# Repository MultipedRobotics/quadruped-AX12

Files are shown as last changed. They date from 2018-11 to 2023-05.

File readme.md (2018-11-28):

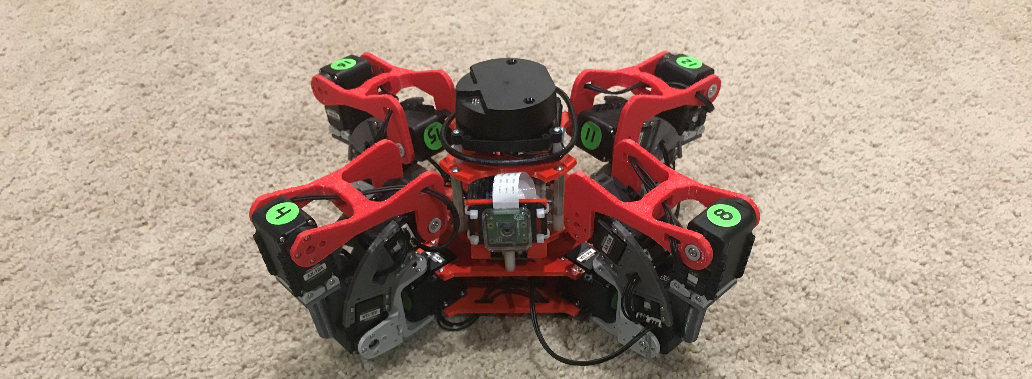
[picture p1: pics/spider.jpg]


# AX-12A Quadruped

Features:

- Robotis AX-12A servos
- 4 legs
    - 4 servos per leg for added degrees of freedom
- Raspberry Pi 3 controlled w/camera
- Robotis lidar for obstacle avoidance and SLAM
- 12V power system
- Externally powered so no limit on run time
    - A battery could be designed and integrated

# Hardware

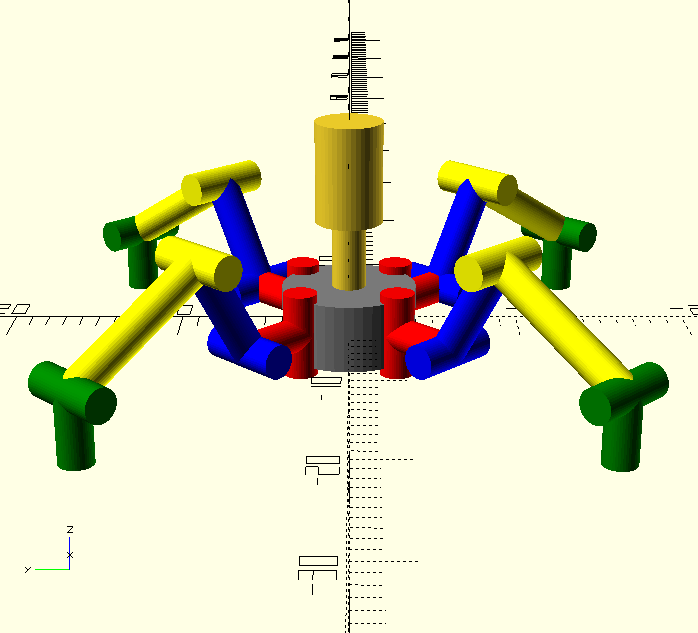
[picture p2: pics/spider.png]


**Still under development**

- [Mechanical Hardware](mechanical/)
- [Electrical Hardware](electrical/)

# Software

Uses [multiped library](https://github.com/MultipedRobotics/multiped/) to control it.

Other SW is TBD until the design is finished

# Software is MIT License

**Copyright (c) 2018 Kevin J. Walchko**

Permission is hereby granted, free of charge, to any person obtaining a
copy of this software and associated documentation files (the
"Software"), to deal in the Software without restriction, including
without limitation the rights to use, copy, modify, merge, publish,
distribute, sublicense, and/or sell copies of the Software, and to
permit persons to whom the Software is furnished to do so, subject to
the following conditions:

The above copyright notice and this permission notice shall be included
in all copies or substantial portions of the Software.

THE SOFTWARE IS PROVIDED "AS IS", WITHOUT WARRANTY OF ANY KIND,
EXPRESS OR IMPLIED, INCLUDING BUT NOT LIMITED TO THE WARRANTIES OF
MERCHANTABILITY, FITNESS FOR A PARTICULAR PURPOSE AND NONINFRINGEMENT.
IN NO EVENT SHALL THE AUTHORS OR COPYRIGHT HOLDERS BE LIABLE FOR ANY
CLAIM, DAMAGES OR OTHER LIABILITY, WHETHER IN AN ACTION OF CONTRACT,
TORT OR OTHERWISE, ARISING FROM, OUT OF OR IN CONNECTION WITH THE
SOFTWARE OR THE USE OR OTHER DEALINGS IN THE SOFTWARE.

---

<p align="center">
    <a rel="license" href="http://creativecommons.org/licenses/by-sa/4.0/">
        
    </a>
    <br />The hardware (mechanical/electrical/documentation) is licensed under a <a rel="license" href="http://creativecommons.org/licenses/by-sa/4.0/">Creative Commons Attribution-ShareAlike 4.0 International License</a>.
</p>

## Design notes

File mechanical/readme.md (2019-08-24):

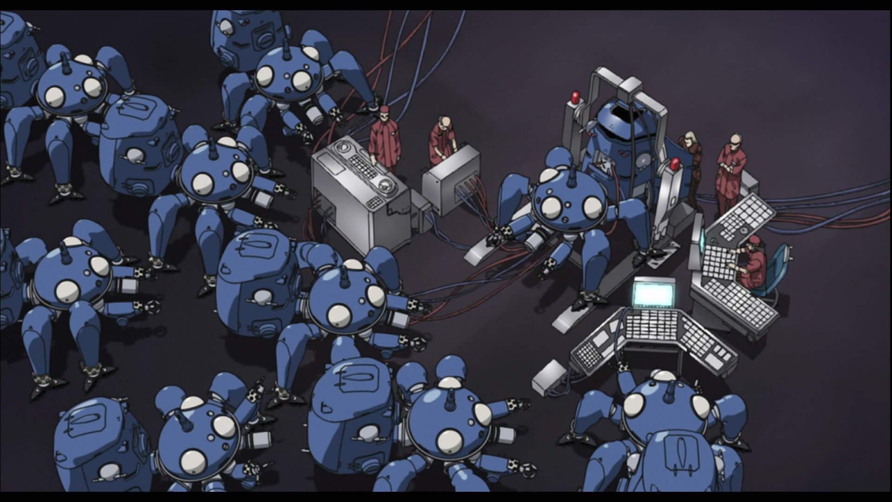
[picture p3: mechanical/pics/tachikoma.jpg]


# AX-12A Mechanical Frame

This is sort of my poor man's tachikoma.

### Leg Parts

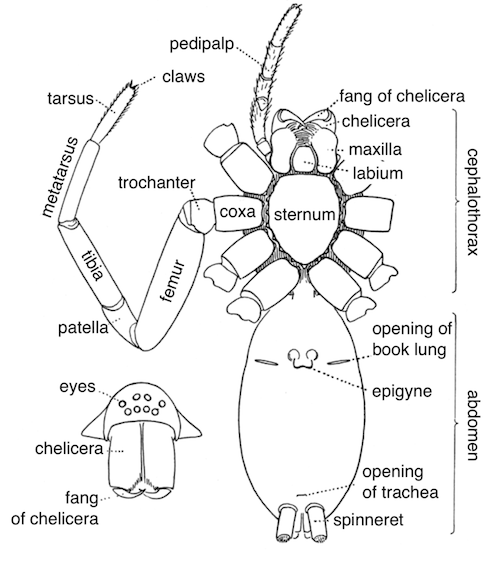
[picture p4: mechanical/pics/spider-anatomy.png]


Part names are based off of a traditional 8 legged spider. Yes, this one only
has 4 legs, but the parts are expensive, so cut me some slack.



- Coxa: red
- Femur: blue
- Tibia: yellow
- Tarsus: green

Each of the legs has 4 addressable smart servos. Leg 1 for example, has servos 1,
2, 3, and 4. Each servo controls a degree of freedom for each leg.

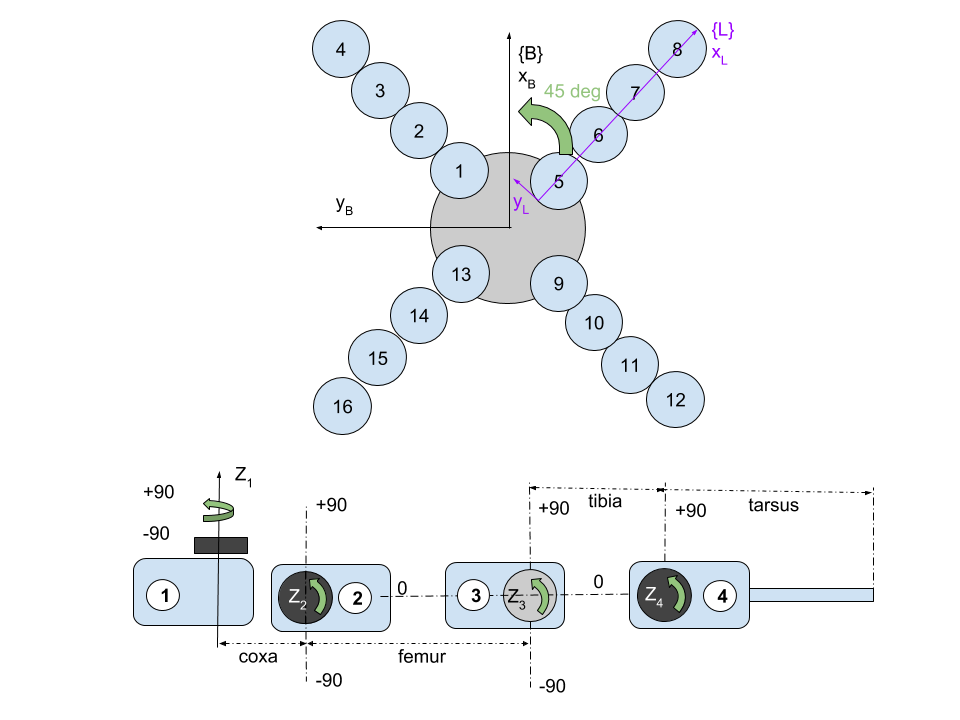
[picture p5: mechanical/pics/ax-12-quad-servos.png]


## Sternum (body)

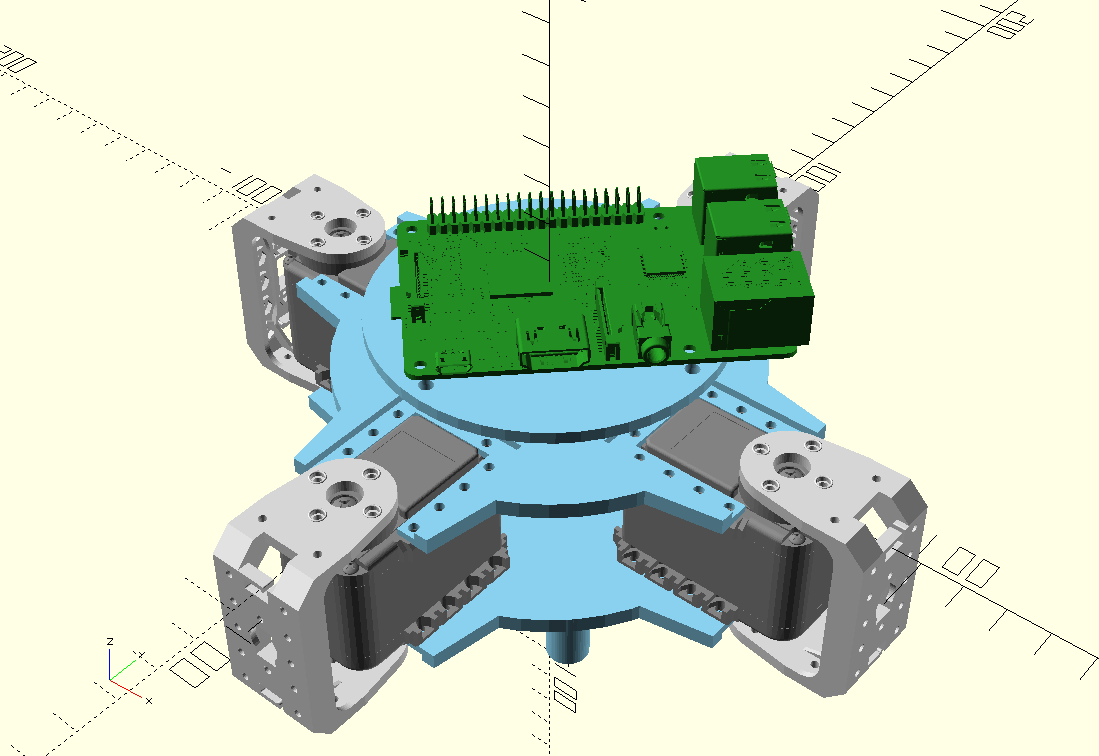
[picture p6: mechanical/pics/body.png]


## Leg

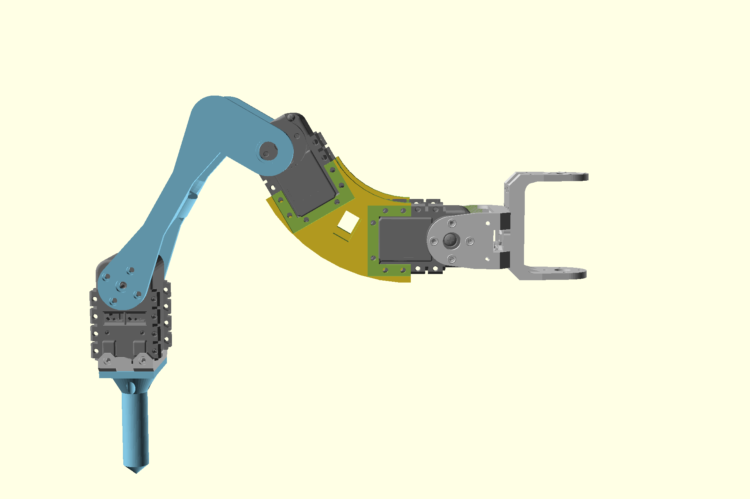
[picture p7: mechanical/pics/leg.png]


## Assembled

The design below shows a new femur design where the part is curved. This
gives the robot a better leg orientation when in the stowed configuration
and the legs are up.

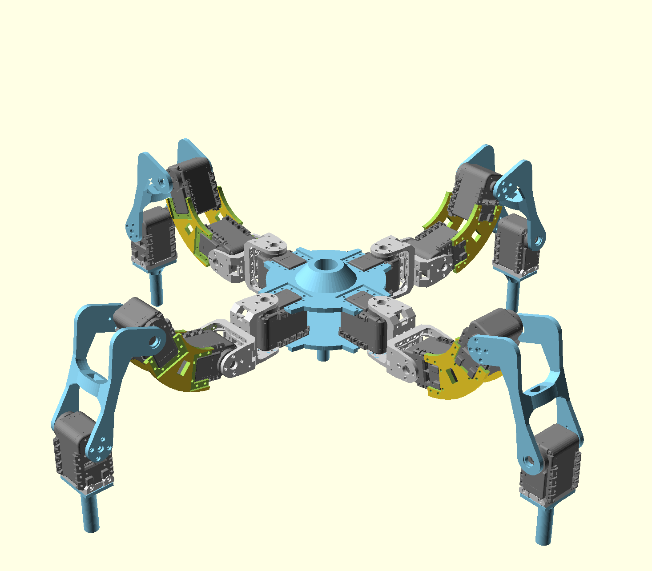
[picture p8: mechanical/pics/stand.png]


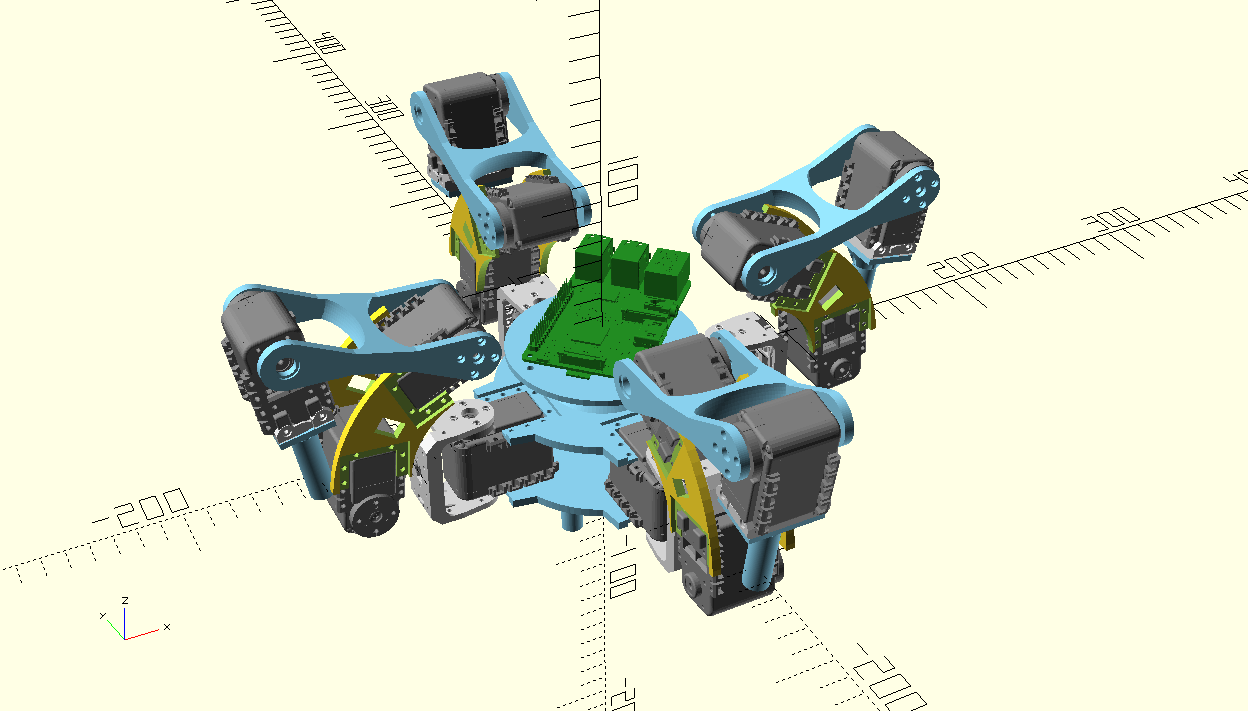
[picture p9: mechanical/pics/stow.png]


# Ideas

I saw [this](https://github.com/adammck/hexapod) design by Adam McKaig and
drew some ideas from it.

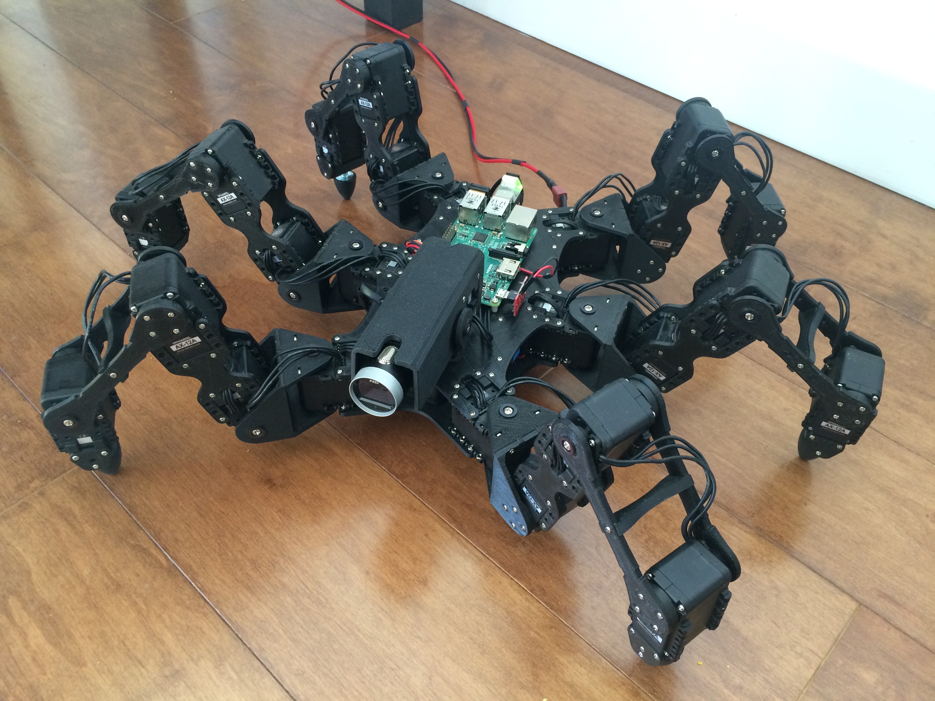
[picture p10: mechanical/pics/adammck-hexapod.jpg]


Also, I always thought the bugs from Starship Troopers were cool.

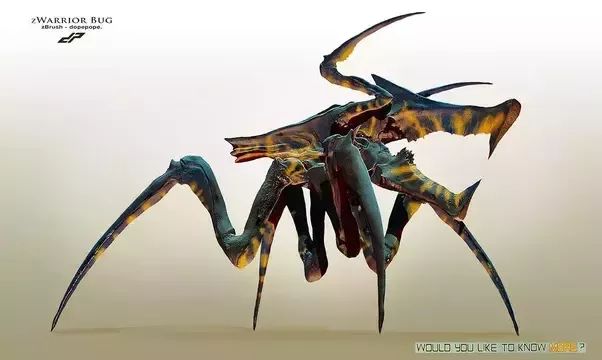
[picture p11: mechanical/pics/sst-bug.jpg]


# Tools

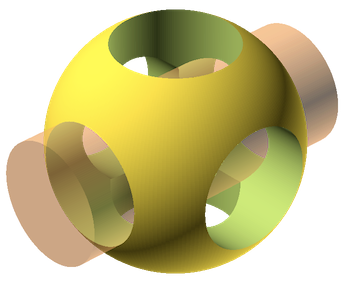
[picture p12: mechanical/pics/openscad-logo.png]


I use [OpenSCAD](http://www.openscad.org/) which is a free solid modeler.

# Bill of Materials (BoM) for Hardware

| Part | Qnty | Each | Cost |
|---|---|---|---|
| AX-12A Servos x6 | 3 | $225  | $675 |
| S1 (M2x6) screws (400 pcs) | 1 | $5 | $5 |
| N1 (M2) nuts (400 pcs) | 1 | $5 | $5 |
| BIOLOID BU/WA Washer/Bushing x10 | 2 | $8 | $16 |
| BOILOID 3Pin Cable Set (25) | 1 | $35 | $35 |
| BIOLOID F2 Servo Bracket x10 | 1 | $7 | $7 |
| BIOLOID F3 Servo Bracket x10 | 1 | $9 | $9 |
| PLA for 3d Printing | 1 | $25 | $25 |
| **Total** | | | $777 |

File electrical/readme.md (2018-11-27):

# Electrical

## Raspberry Pi

Adaptor board to connect the RPi to sensors/actuators

## Sensors

[360 Laser Distance Sensor LDS-01 (LIDAR)](http://www.robotis.us/360-laser-distance-sensor-lds-01-lidar/)

## Power

Power distribution board just passes the input power to the 16 AX12 servos and the RPi/Sensors.

### [Pololu 5V Buck Regulator](https://www.pololu.com/product/2851)

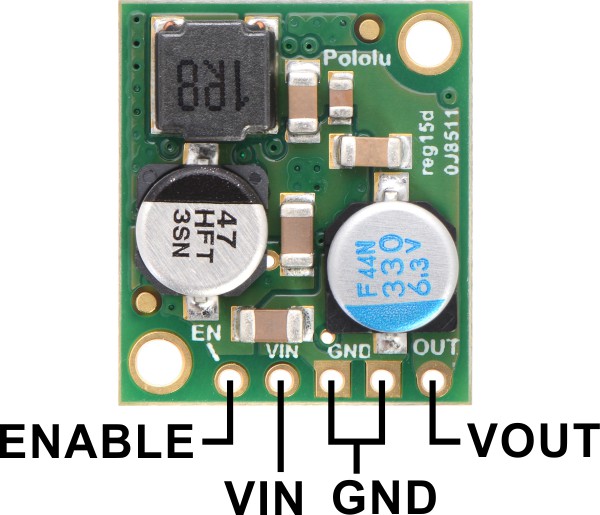
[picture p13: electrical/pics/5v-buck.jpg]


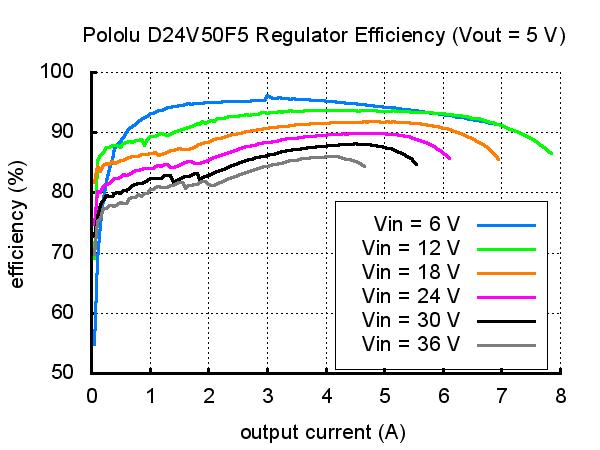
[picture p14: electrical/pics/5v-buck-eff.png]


### [Pololu 12V Buck Regulator](https://www.pololu.com/product/2885)

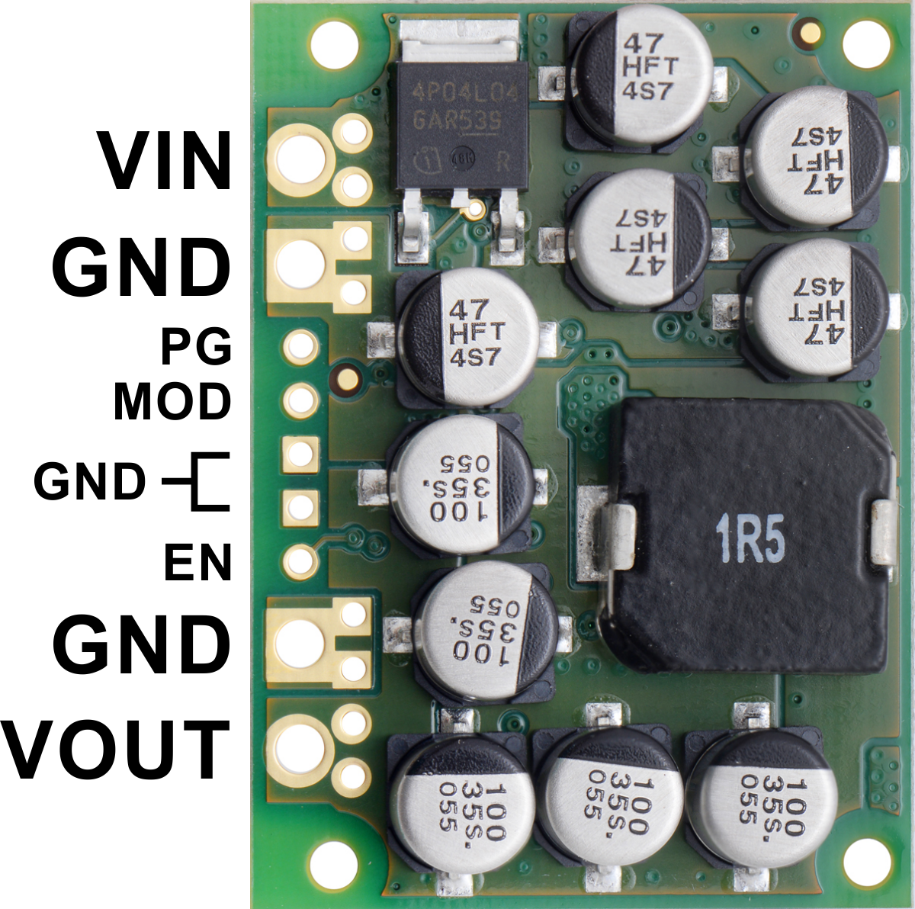
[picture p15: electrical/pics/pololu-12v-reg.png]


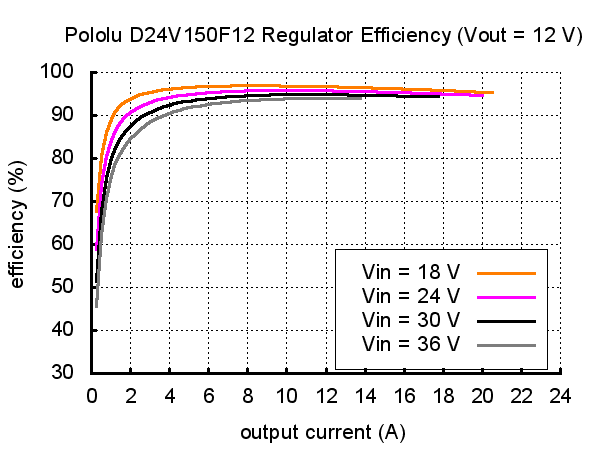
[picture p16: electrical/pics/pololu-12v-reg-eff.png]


# Bill of Materials (BoM)

| Part | Qnty | Each | Cost |
|---|---|---|---|
| Raspberry Pi | 1 | $35 | $35 |
| Lidar | 1 | $180 | $180 |
| RPi AX12 adaptor board | 1 | $20 est. | $20 |
| Power Distrobution board | 1 | $30 est. | $30 |
| Pololu 12V Buck Regulator | 2 | $40 | $80 |
| Pololu 5V Buck Regulator | 1 | $15 | $15 |
| **Total** | | | **$360** |

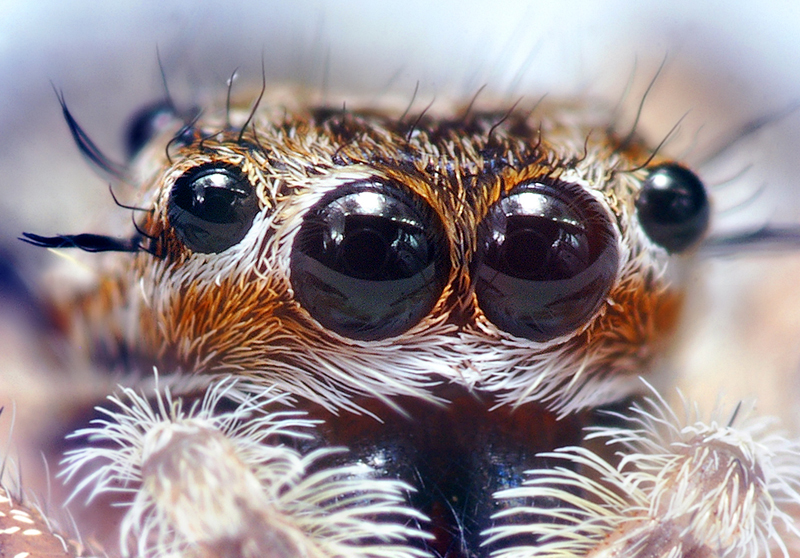
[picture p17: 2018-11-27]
mechanical/pics/spider-head.jpg

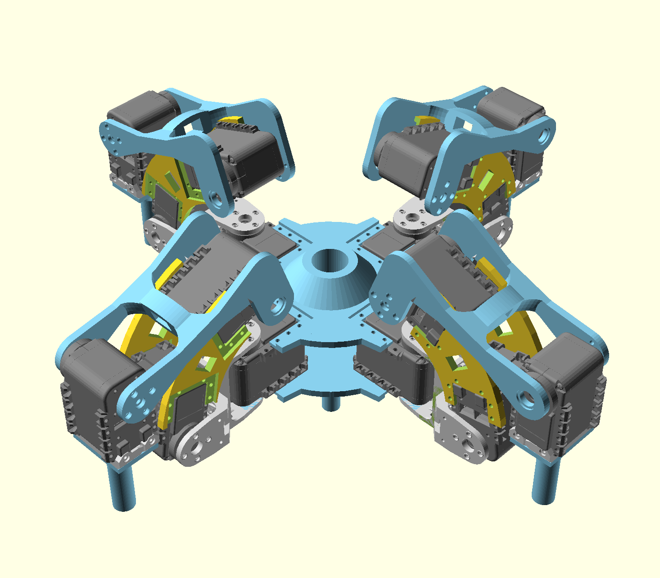
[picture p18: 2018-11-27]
mechanical/pics/robot-stow.png

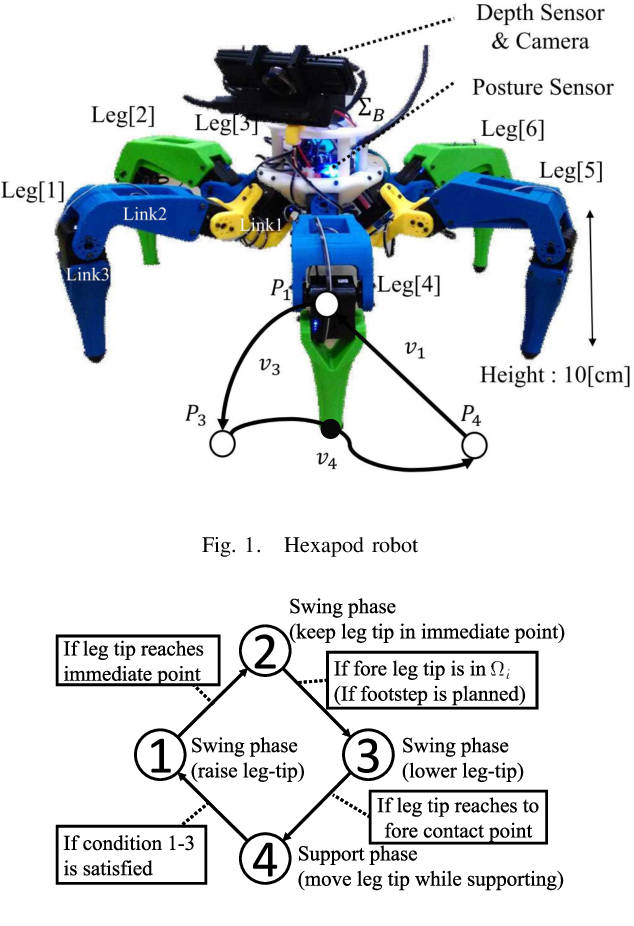
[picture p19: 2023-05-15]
docs/leg-design/2-Figure1-1.png

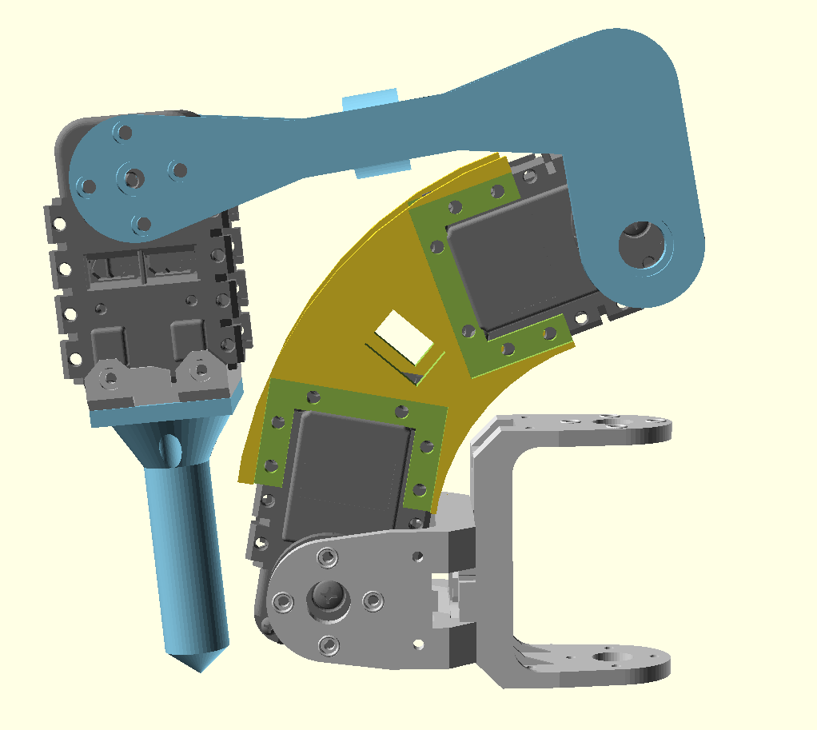
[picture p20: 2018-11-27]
mechanical/pics/leg-2.png

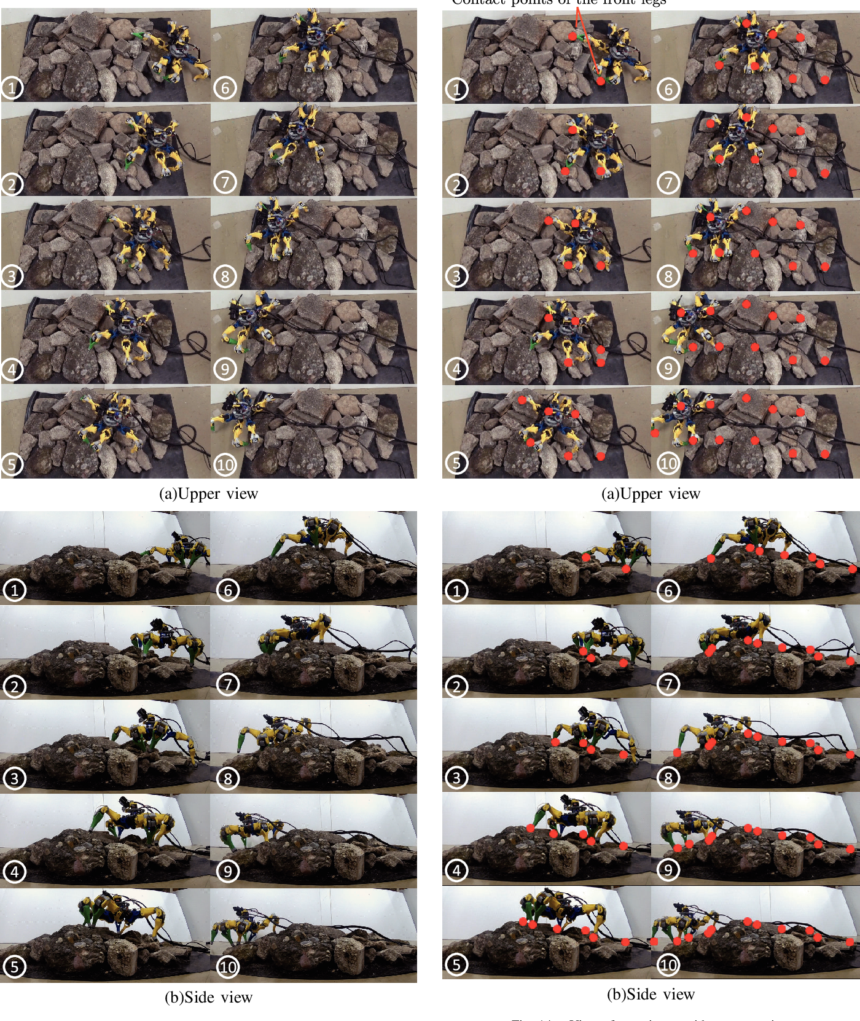
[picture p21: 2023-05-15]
docs/leg-design/7-Figure14-1.png

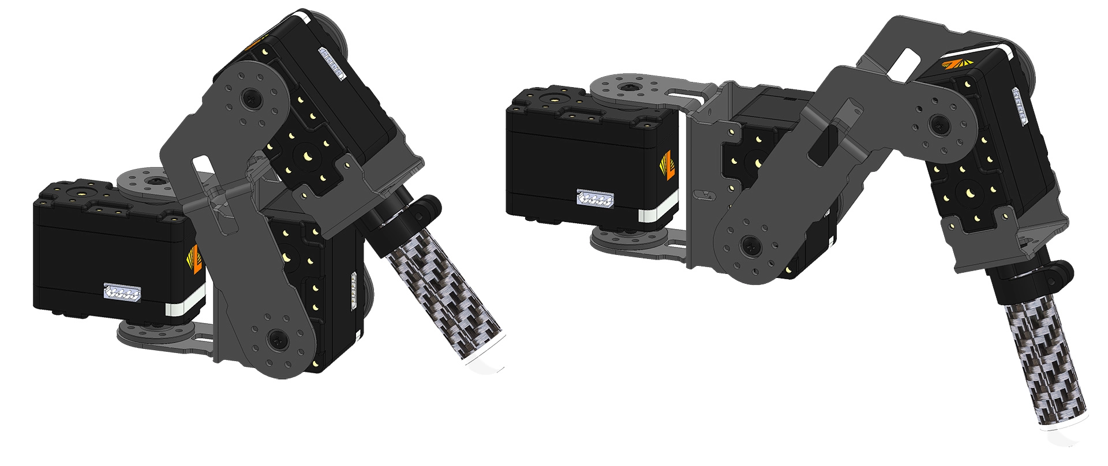
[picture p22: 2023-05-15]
docs/leg-design/92f82586bec9464cacff4a840627ed5457931b34.webp

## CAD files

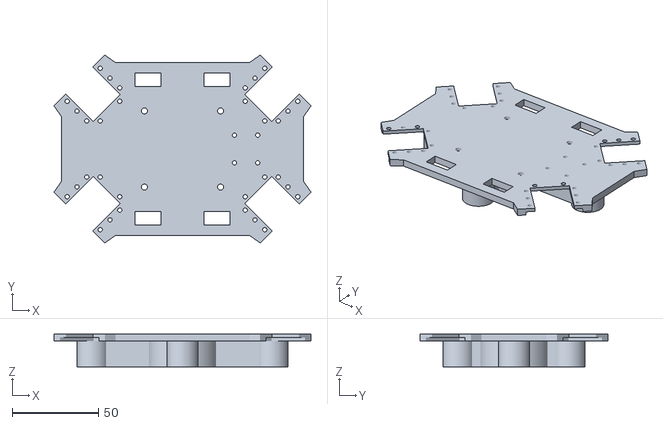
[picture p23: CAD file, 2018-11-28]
mechanical/stl/bottom-rect-5.stl
148.6 x 108.6 x 19.0

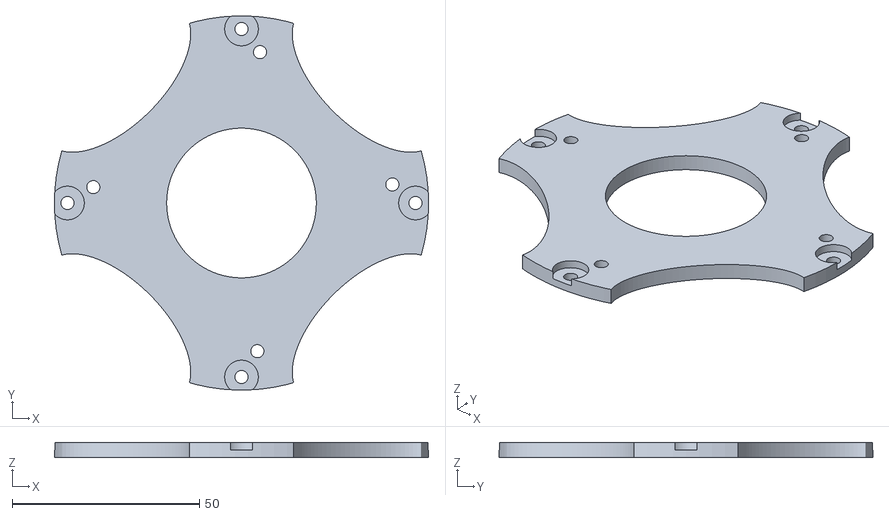
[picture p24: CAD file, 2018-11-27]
mechanical/stl/lidar_base-3.stl
100.0 x 99.9 x 4.00

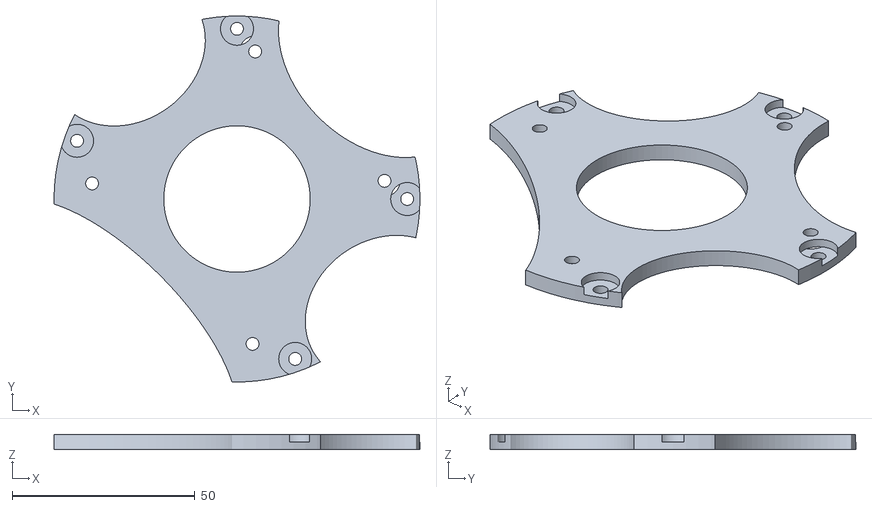
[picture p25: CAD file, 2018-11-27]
mechanical/stl/lidar_base-4.stl
100.0 x 99.9 x 4.00

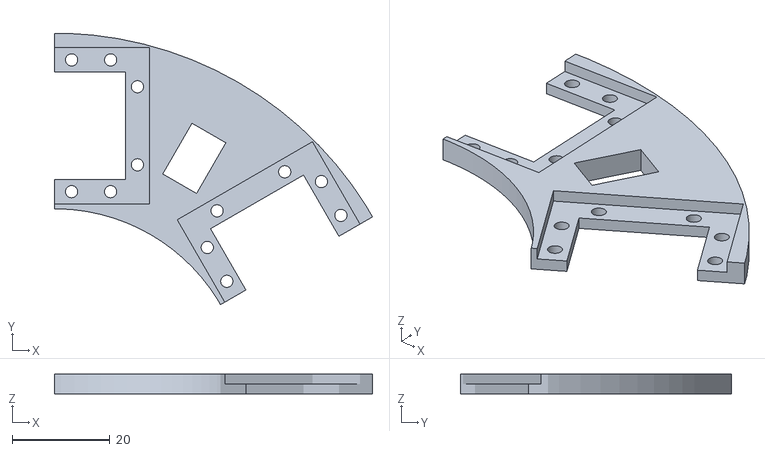
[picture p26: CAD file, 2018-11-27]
mechanical/stl/femur.stl
65.2 x 55.6 x 4.00

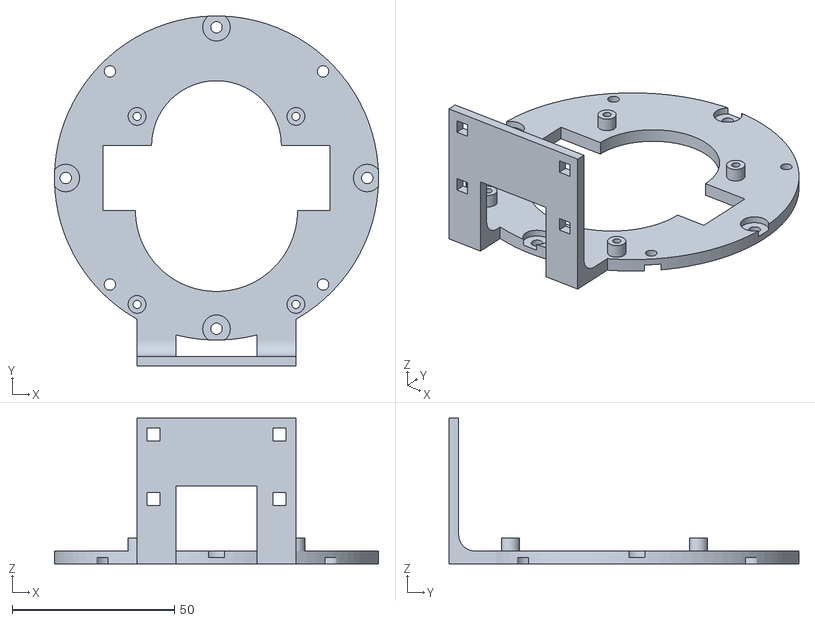
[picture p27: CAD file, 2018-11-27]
mechanical/stl/rpi_base-4.stl
100.0 x 108.0 x 45.0

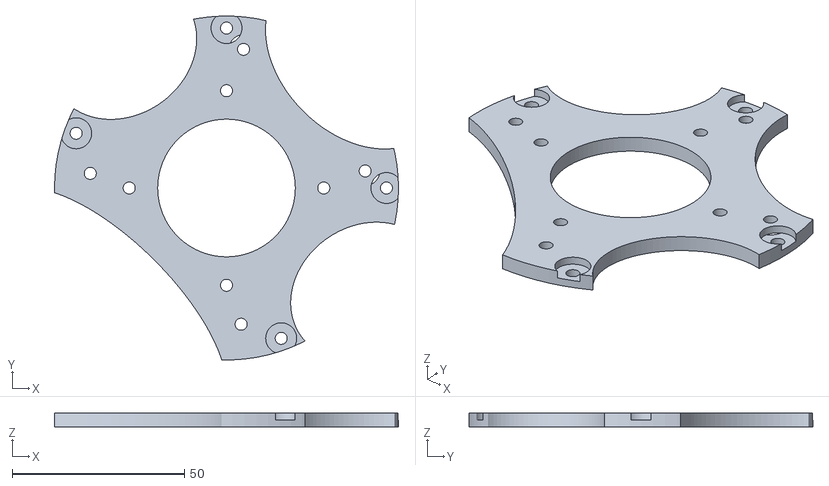
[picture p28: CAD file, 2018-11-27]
mechanical/stl/lidar_base-5.stl
100.0 x 99.9 x 4.00

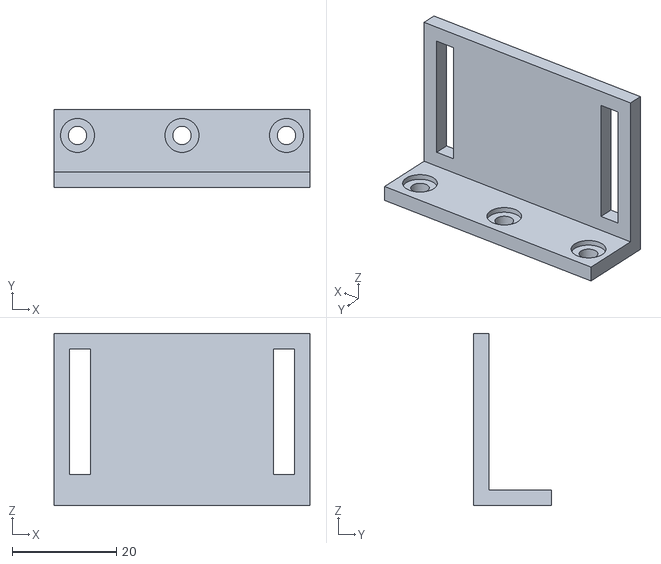
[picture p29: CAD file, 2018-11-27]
mechanical/stl/camera-mount.stl
49.0 x 15.0 x 33.0

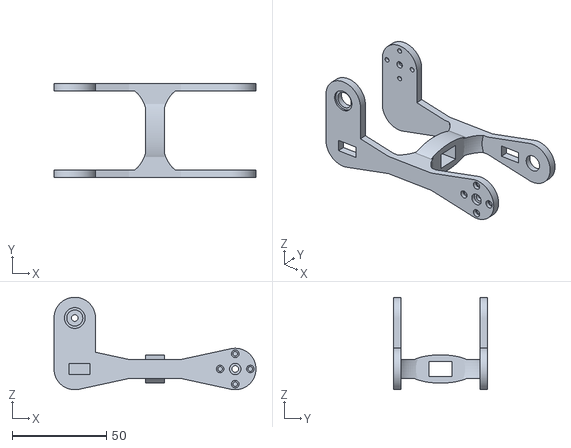
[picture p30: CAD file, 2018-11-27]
mechanical/stl/tibia-4.stl
107.0 x 50.0 x 49.0

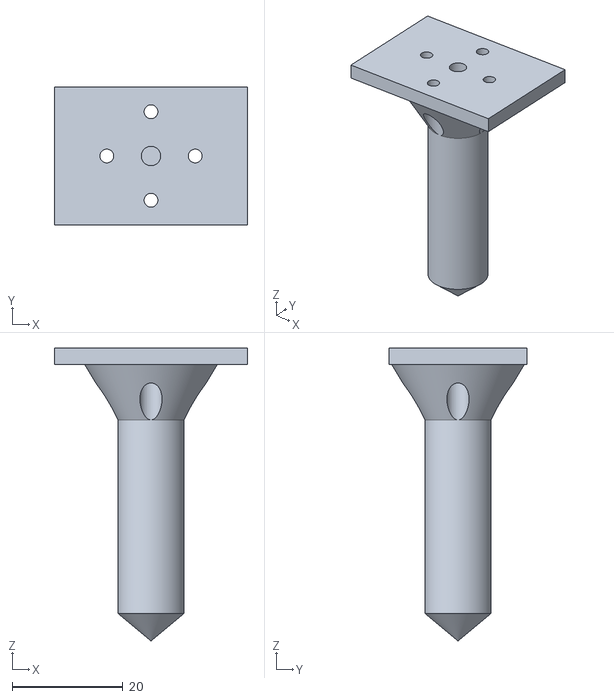
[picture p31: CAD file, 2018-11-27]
mechanical/stl/tarsus.stl
35.0 x 25.0 x 53.0

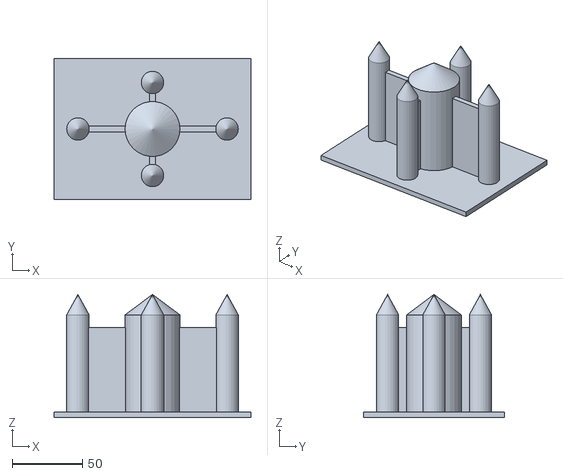
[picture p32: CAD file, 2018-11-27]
mechanical/stl/stand.stl
140.0 x 100.0 x 87.5

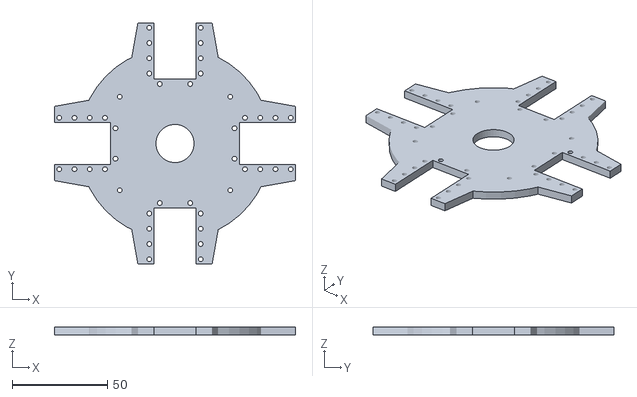
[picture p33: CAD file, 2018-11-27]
mechanical/stl/ax12-base.stl
126.5 x 126.5 x 4.00

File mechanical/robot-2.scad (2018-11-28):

$fn = 90;

// library folder
use <lib/robotis_parts.scad>;
use <lib/misc.scad>;
use <lib/pi.scad>;
use <lib/lidar.scad>;

// this folder
use <tibia.scad>;
use <femur.scad>;
use <tarsus.scad>;
use <coxa.scad>;
//use <head.scad>;
use <sternum-2.scad>;
use <power.scad>;

//module leg45(a1=0, a2=0){
//    translate([20,-15,15]) rotate([0,0,0]){
//        length=60;
//        femur(length, 45);
//        translate([0,0,-35]) coxa(length, 45);
//        translate([-3,20-4,-13]) rotate([0,0,90]) ax12();
//        translate([56,-7,-13]) rotate([0,0,270-45]) ax12();
//        rotate([90,0,-45]) translate([60+85/2*cos(a1),-15, -35-85/2*sin(a1)]) rotate([0,a1,0]){
//            tibia();
//            translate([43+15*cos(a2),-2.75,-15*sin(a2)]) rotate([0,-90,90]) rotate([0,0,-a2]) {
//                ax12();
//
//                rotate([-90,0,0]) translate([0,4,-25]) rotate([90,0,0]) f3();
//                rotate([-90,0,0]) translate([0,4,-78]) rotate([0,0,90]) tarsus();
//            }
//        }
//    }
//}

module leg60(a1=0, a2=0,COLOR1,COLOR2){
    translate([18,-16.5,15]) {
        length=60;
        // 60 degrees
        color(COLOR2) femur(length, 60);
        translate([0,0,-35]) color(COLOR2) femur(length, 60);

        translate([-3,20-4,-13]) rotate([0,0,90]) ax12();
        translate([51,-13,-13]) rotate([0,0,270-60]) ax12();
//        rotate([90,0,-60]) translate([53+(89/2)*cos(a1)+27*sin(a1),-15, -38-(27+89/2)*sin(a1)+27*cos(a1)]) rotate([0,a1,0]) {
        rotate([90,0,-60]) translate([53+(89/2)*cos(a1)+27*sin(a1),-15, -18-(27+89/2)*sin(a1)+37*cos(a1)]) rotate([0,a1,0]) {
            rotate([180,0,0]) color(COLOR1) tibia();
            translate([43+15*cos(a2),-2.75,-15*sin(a2)]) rotate([0,-90,90]) rotate([0,0,-a2]) {
                ax12();

                rotate([-90,0,0]) translate([0,4,-25]) rotate([90,0,0]) f3();
                rotate([-90,0,0]) translate([0,4,-78]) rotate([0,0,90]) color(COLOR2) tarsus();
            }
        }
    }
}

module leg(femur_angle, tibia_angle, tarsus_angle,COLOR1,COLOR2){
    rotate([-90,0,0]) coxa();  // standard robotis parts
    rotate([-90,-femur_angle,0]) leg60(tibia_angle,tarsus_angle,COLOR1,COLOR2);
}

module piFootPrint(depth=10){
    hole = 2.8; // mm
    dx = 58;
    dy = 49;
    translate([-dx/2,-dy/2,0]){
        /* cylinder(h=depth, d=hole, center=true);
        translate([dx,0,0]) cylinder(h=depth, d=hole, center=true);
        translate([0,dy,0]) cylinder(h=depth, d=hole, center=true);
        translate([dx,dy,0]) cylinder(h=depth, d=hole, center=true); */
        M2(20);
        translate([dx,0,0]) M2(20);
        translate([0,dy,0]) M2(20);
        translate([dx,dy,0]) M2(20);
    }
}

module M2standoff(x,y,z,h){
    dia = 2.5;
    wide = 3;

    translate([x,y,z]) difference(){
        cylinder(h=h, d=dia+wide);
        cylinder(h=4*h, d=dia, center=true);
    }
}

module cameramount(thick){
    offset = 15;
    translate([0,-3,0]){  // move to avoid screw holes
    // connects to base plate
    difference(){
        translate([-49/2,0,0]) cube([49, 15, thick]);
        translate([-25/2,-1,-1]) cube([25, 20, 2*thick]); // screw cutout
    }
    // camera mount back
    difference(){
        translate([-49/2,0,0])cube([49, 3, 30+offset]);
        translate([-49/2+3,-1,3+offset]) cube([4, 10, 4]);
        translate([-49/2+3,-1,3+offset+20]) cube([4, 10, 4]);
        translate([49/2-7,-1,3+offset]) cube([4, 10, 4]);
        translate([49/2-7,-1,3+offset+20]) cube([4, 10, 4]);
        translate([-25/2,-1,-1])cube([25, 10, 25]);  // cable/sd card cutout
    }
    // curved edges
    difference(){
        translate([-49/2,0,4]) cube([49, 8, 5]);
        translate([-49/2-1,5+3,4+5]) rotate([0,90,0]) cylinder(h=55, d=10);
        translate([-25/2,-1,-1]) cube([25, 20, 40]); // screw cutout
    }
}
}

module rpi_base(){
    difference(){
        // main deck
        cylinder(h=4, d=100);

        // cable cutouts
        cube([70,20,20], center=true);
        translate([0,-10,0]) cylinder(h=10, d=50, center=true);
        translate([0,10,0]) cylinder(h=20, d=40, center=true);

        // alt imu mount point
        rotate([0,180,0]) translate([0,0,-4]){
            y = 5;
            translate([38, 23+y, 0]) M2(20);
            translate([38, y, 0]) M2(20);
        }

        // screws to bottom (legs)
        translate([50-5/2-1, 0, 0]) M3(20);
        translate([-50+5/2+1, 0, 0]) M3(20);
        translate([0, 50-5/2-1, 0]) M3(20);
        translate([0, -50+5/2+1, 0]) M3(20);

        // screws to top (lidar)
        rotate([0,180,45]) translate([0,0,-4]){
            rotate([0,0,20]) translate([50-5/2-1, 0, 0]) M3(20);
            translate([-50+5/2+1, 0, 0]) M3(20);
            translate([0, 50-5/2-1, 0]) M3(20);
            rotate([0,0,-20]) translate([0, -50+5/2+1, 0]) M3(20);
        }

        rotate([0,180,90]) translate([10,0,-4]) piFootPrint();
    }

    // imu standoffs
    height = 4;  // height above plate
    y = 5;
    M2standoff(-38,23+y,4,height);
    M2standoff(-38,y,4,height);

    // pi standoffs
    dx = 58;
    dy = 49;
    height = 4;  // height above plate
    rotate([0,0,90]) translate([-dx/2,-dy/2,0]) {
        M2standoff(dx-10,0,4,height);
        M2standoff(-10,0,4,height);
        M2standoff(dx-10,dy,4,height);
        M2standoff(-10,dy,4,height);
    }

    translate([0,-55,0]) cameramount(4);
}

module lidar_base(){
    dia = 100;
    difference(){
        cylinder(h=4, d=100);
        cylinder(h=10, d=40, center=true);

        // screws to rpi deck
        m3d = 6;
        translate([50-5/2-1, 0, 0]) M3Nut(20); //cylinder(h=19,d=m3d, center=true);
        rotate([0,0,-20]) translate([-50+5/2+1, 0, 0]) M3Nut(20);
        translate([0, 50-5/2-1, 0]) M3Nut(20);
        rotate([0,0,20]) translate([0, -50+5/2+1, 0]) M3Nut(20);
//}{
        // ydlidar/lds-01 lidar mount
        rotate([0,180,45]) translate([3,0,-4]){
            translate([22,31,0]) M3(20);
            translate([22,-31,0]) M3(20);
            translate([-35,25,0]) M3(20);
            translate([-35,-25,0]) M3(20);
        }

        // rpylidar - tbd

        // hokuyo urg mount
        rotate([0,180,45]) translate([0,0,-4]){
            translate([20,20,0]) M3(20);
            translate([20,-20,0]) M3(20);
            translate([-20,20,0]) M3(20);
            translate([-20,-20,0]) M3(20);
        }

        // skeletonizing
        translate([dia/3+4, dia/3+4, -2]) rotate([0,0,-45]) scale([1.2,.85,1]) cylinder(h=10, d=50); // back
        translate([-dia/4-5, dia/2.5, -2]) rotate([0,0,35]) scale([.90,.75,1]) cylinder(h=10, d=50); // right
        //translate([dia/3, -dia/3, -2]) rotate([0,0,45]) scale([1,.5,1]) cylinder(h=10, d=50);
        translate([dia/2.5, -dia/4-5, -2]) rotate([0,0,35]) scale([.90,.75,1]) cylinder(h=10, d=50); // left
        translate([-dia/3, -dia/3, -2]) rotate([0,0,-45]) scale([1.75,.70,1]) cylinder(h=10, d=50); // front
    }
}


//leg(10,140,20);  // stand
//leg(100,180,70);  // stow
//leg(100,170,85);
//leg(10,140,20);

/* module upper(){
    translate([0,26,4+4]) power_board();
    translate([0,-26,4+4]) rotate([0,0,180]) power_board();

    color("silver") translate([50-5/2-1, 0, 4]) cylinder(h=19,d=5);
    color("silver") translate([-50+5/2+1, 0, 4]) cylinder(h=19,d=5);
    color("silver") translate([0, 50-5/2-1, 4]) cylinder(h=19,d=5);
    color("silver") translate([0, -50+5/2+1, 4]) cylinder(h=19,d=5);

    translate([0,0,4+19]) {  // top: 4mm  stand off: 19 mm
        rotate([0,0,90]) translate([0,0,4+19]) rpi3();
        color("red") rpi_base();
    }
} */


// stand: 10, 100, 55
// stow: 100 180 70

module fullrobot(femur_angle, tibia_angle, tarsus_angle){
    length = 140;
    width = 100;

    // COLOR1 = "skyblue";
    COLOR1 = "red";
    COLOR2 = "silver";

    color(COLOR1) top2(length, width);
    translate([0,30,10]) power_board();
    translate([0,-30,10]) rotate([0,0,180]) power_board();

    translate([0,0,25]) {
        color(COLOR1) rpi_base();
        translate([0,-60,20]) rotate([90,0,0]) picamera();
        rotate([0,0,90]) translate([2,0,6]) rpi3();
        translate([0,0,30]) rotate([0,0,45]) color(COLOR1) lidar_base();
        translate([0,0,34]) rotate([0,0,-90]) rplidar();
    }
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

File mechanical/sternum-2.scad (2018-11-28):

//use <lib/robotis_parts.scad>;
use <power.scad>;
use <lib/misc.scad>;
use <base.scad>;

//$fn=100;

module spar(L){
    linear_extrude(4){
        hull(){
            circle(d=1.25*40);
//            translate([2.25*40/3-3,0,0]) square(35, center=true);
            translate([2.25*40/3-3,0,0]) square(35, center=true);
        }
    }
}

module servo_mnt(){
    d = 2.5;
    w = 22; // center servo
    l = 35; // center servo
    s = 38.5-2.5;
    h=20;

    translate([32,-20,-1]) cube([20,40,h],center=false);
    translate([2.5,-w/2,-1]) cube([l,w,h],center=false);

    // bottom holes
    translate([0,8,-1]) cylinder(h,d=d);
    translate([0,-8,-1]) cylinder(h,d=d);

    // right holes
    translate([5.5,-27/2,-1]) cylinder(h,d=d);
    translate([5.5+8,-27/2,-1]) cylinder(h,d=d);
    translate([5.5+16,-27/2,-1]) cylinder(h,d=d);
    translate([5.5+24,-27/2,-1]) cylinder(h,d=d);

    // left holes
    translate([5.5,27/2,-1]) cylinder(h,d=d);
    translate([5.5+8,27/2,-1]) cylinder(h,d=d);
    translate([5.5+16,27/2,-1]) cylinder(h,d=d);
    translate([5.5+24,27/2,-1]) cylinder(h,d=d);

    // make layer thinner so M2x6 screws work
    translate([-2.5,-32/2,2]) cube([40,32,5], center=false);

    // make shorter - x: 25 mm should give 3 holes
    translate([25,-60/2,-10]) cube([40,60,20], center=false);
}

/* module base(D){
    servo = 35/2+2.25*40/2;
    h=4;
    difference(){
        spar_len = 30;
        difference(){
            union(){
                cylinder(h,d=.75*D);
                rotate([0,0,0]) translate([spar_len,0,0])  spar(D);
                rotate([0,0,90]) translate([spar_len,0,0]) spar(D);
                rotate([0,0,180]) translate([spar_len,0,0]) spar(D);
                rotate([0,0,270]) translate([spar_len,0,0]) spar(D);
            }
            translate([0,0,-1]) cylinder(20,d=20);  // cable hole
            rotate([0,0,0])  translate([servo/2,0,0]) servo_mnt();
            rotate([0,0,90])  translate([servo/2,0,0]) servo_mnt();
            rotate([0,0,180])  translate([servo/2,0,0]) servo_mnt();
            rotate([0,0,270])  translate([servo/2,0,0]) servo_mnt();
        }
		// shorten the spars
		rotate([0,0,0])  translate([servo-6,-60/2,-10]) cube([40,60,20], center=false);
		rotate([0,0,90])  translate([servo-6,-60/2,-10]) cube([40,60,20], center=false);
		rotate([0,0,180])  translate([servo-6,-60/2,-10]) cube([40,60,20], center=false);
		rotate([0,0,270])  translate([servo-6,-60/2,-10]) cube([40,60,20], center=false);
        // make layer thinner so M2x6 screws work
        rotate([0,0,0])  translate([servo/2-2.5,-32/2,2]) cube([40,32,5], center=false);
        rotate([0,0,90])  translate([servo/2-2.5,-32/2,2]) cube([40,32,5], center=false);
        rotate([0,0,180])  translate([servo/2-2.5,-32/2,2]) cube([40,32,5], center=false);
        rotate([0,0,270])  translate([servo/2-2.5,-32/2,2]) cube([40,32,5], center=false);
    }
} */

/* module top(){
	thick = 4;
    base(135);
    neck = 15;
    difference(){
        translate([0,0,neck/2+thick/2]) cylinder(neck, d2=30, d1=55, center=true);
        translate([0,0,neck/2+thick/2]) cylinder(2*neck,d=20, center=true);
    }
} */

/* module bottom(){
    rotate([180,0,0])  translate([0,0,32]) base(135);

    // center grab point
    dia = 50;
    h = 15;
    translate([0,0,-32-h]) difference(){
        cylinder(h, d=dia);
        translate([dia/1.75,0,0]) cube([dia/2,dia, 2*h], center=true);
        translate([-dia/1.75,0,0]) cube([dia/2,dia, 2*h], center=true);
    }

    // corner stablizers
    sdia = 10;
    rotate([0,0,45]) translate([.75*135/2-sdia/2,0,-32-h]) cylinder(h, d=sdia);
    rotate([0,0,135]) translate([.75*135/2-sdia/2,0,-32-h]) cylinder(h, d=sdia);
    rotate([0,0,225]) translate([.75*135/2-sdia/2,0,-32-h]) cylinder(h, d=sdia);
    rotate([0,0,315]) translate([.75*135/2-sdia/2,0,-32-h]) cylinder(h, d=sdia);
} */

module spar2(){
    // make an unnecessarily fancy shape that mostly gets removed ... replace with simplier solution?
    linear_extrude(4){
        hull(){
            circle(d=1.25*40);
            translate([27,0,0]) square(35, center=true);
        }
    }
}


module base_wide2(L, W){
    servo = 35/2+2.25*40/2;
    h=4;
    /* tiex = 20;
    tiey = W/2;
    tiedia = 12; */
    angle = atan2(W/2,L/2);
    echo("angle",angle);
    difference()
    {
//        spar_len = 50;  // 50
        spar_len = 30;
        offset = 31;  // distance from 45 deg mid-line
        shift = L/2 - sqrt(50*50+50*50)*cos(45);
        echo("shift", shift);
//        shift = 0;
        union(){
            translate([-L/2,-W/2,0]) cube([L,W,h], center=false);
            translate([shift,0,0]) rotate([0,0,45]) translate([spar_len,0,0]) spar2();
            translate([-shift,0,0]) rotate([0,0,135]) translate([spar_len,0,0]) spar2();
            translate([-shift,0,0]) rotate([0,0,225]) translate([spar_len,0,0]) spar2();
            translate([shift,0,0]) rotate([0,0,315]) translate([spar_len,0,0]) spar2();

            // power cord tiedown
            //translate([tiex,tiey,0]) cylinder(h, d=tiedia);

            // push button
            // translate([32,0,0]) cylinder(10,d=19, center=false);
        }
        // translate([0,0,-1]) cylinder(20,d=20);  // cable hole
        //cube([50,20,60], center=true);  // cable hole
        // power cord tiedown
        //translate([tiex,tiey,0]) cylinder(4*h, d=tiedia/2, center=true);

        // push button
        // translate([32,0,0]) cylinder(40,d=16.5, center=true);

        translate([shift,0,0]) rotate([0,0,45]) translate([offset,0,0]) servo_mnt();
        translate([-shift,0,0]) rotate([0,0,135]) translate([offset,0,0]) servo_mnt();
        translate([-shift,0,0]) rotate([0,0,225]) translate([offset,0,0]) servo_mnt();
        translate([shift,0,0]) rotate([0,0,315]) translate([offset,0,0]) servo_mnt();

    }
}

/* module M2standoff(x,y,z,h){
    dia = 2.5;
    wide = 3;

    translate([x,y,z]) difference(){
        cylinder(h=h, d=dia+wide);
        cylinder(h=4*h, d=dia, center=true);
    }
} */

module top2(l,w){
    thick = 4;
    tiex = 20;
    tiey = w/2;
    tiedia = 12;
    difference(){
        union(){
            base_wide2(l, w);
            translate([0,26,0]) powerStandoff(8);
            translate([0,-26,0]) rotate([0,0,180]) powerStandoff(8);
            // power cord tiedown
            translate([tiex,tiey,0]) cylinder(thick, d=tiedia);
        }
        cube([50,20,60], center=true);  // cable hole

        // power cord tiedown
        translate([tiex,tiey,0]) cylinder(4*thick, d=tiedia/2, center=true);

        // stand-offs
        m3 = 3.1;
        translate([50-5/2-1, 0, 4]) cylinder(h=19,d=m3, center=true);
        translate([-50+5/2+1, 0, 4]) cylinder(h=19,d=m3, center=true);
        translate([0, 50-5/2-1, 4]) cylinder(h=19,d=m3, center=true);
        translate([0, -50+5/2+1, 4]) cylinder(h=19,d=m3, center=true);

        // pan head counter sinks
        m3d = 6;
        m3h = 2.5;
        translate([50-5/2-1, 0, -0.5]) cylinder(h=m3h,d=m3d, center=false);
        translate([-50+5/2+1, 0, -0.5]) cylinder(h=m3h,d=m3d, center=false);
        translate([0, 50-5/2-1, -0.5]) cylinder(h=m3h,d=m3d, center=false);
        translate([0, -50+5/2+1, -0.5]) cylinder(h=m3h,d=m3d, center=false);

        // holes for standoffs
        translate([0,26,0]) powerFootPrint();
        translate([0,-26,0]) rotate([0,0,180]) powerFootPrint();
    }

//    thick = 4;
//    neck = 15;
//    difference(){
//        translate([0,0,neck/2+thick/2]) cylinder(neck, d2=30, d1=2*w/3, center=true);
//        translate([0,0,neck/2+thick/2]) cylinder(2*neck,d=20, center=true);
//    }
}

/* module interface(h, dia){
    difference(){
        cylinder(h=h,d=dia);
        translate([0,0,-1]) cylinder(h=h,d2=0, d1=dia-1);
    }
} */

module bottom2(l,w){

    difference(){
        rotate([180,0,0])  translate([0,0,32]) base_wide2(l, w);

        // cable holes
        translate([20,w/2-10,-32]) cube([15,8,10], center=true);
        translate([-20,w/2-10,-32]) cube([15,8,10], center=true);
        translate([20,-w/2+10,-32]) cube([15,8,10], center=true);
        translate([-20,-w/2+10,-32]) cube([15,8,10], center=true);

        // power distro board mounting holes
        hbolt = 100;
        translate([22,22,-32])   M3(hbolt);
        translate([-22,22,-32])  M3(hbolt);
        translate([22,-22,-32])  M3(hbolt);
        translate([-22,-22,-32]) M3(hbolt);

        // 5V buck converter
        box = 30;
        boy = -8;
        bodx = 13.5;
        body = 16;
        translate([box,boy,-32])   M2(hbolt);
        translate([box+bodx,boy,-32])  M2(hbolt);
        translate([box,boy+body,-32])  M2(hbolt);
        translate([box+bodx,boy+body,-32]) M2(hbolt);
    }
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

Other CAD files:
mechanical/stl/rpi_base-5.stl
mechanical/stl/bottom-rect-4.stl
mechanical/archive/tmp/coxa-r.stl
mechanical/base.scad
mechanical/camera-mount.scad
docs/openscad/quad-4-links.scad
mechanical/archive/femur.scad
mechanical/archive/head.scad
mechanical/archive/leg.scad
mechanical/archive/misc.scad
mechanical/archive/new-head-2.scad
mechanical/archive/new-head-3.scad
mechanical/archive/new-head-4.scad
mechanical/archive/new-head.scad
mechanical/archive/parts.scad
mechanical/archive/pi.scad
mechanical/archive/quad.scad
mechanical/archive/robotis_parts.scad
mechanical/archive/sternum.scad
mechanical/archive/tmp/femur.scad
mechanical/archive/tmp/leg.scad
mechanical/coxa.scad
mechanical/femur.scad
mechanical/power.scad
mechanical/tarsus.scad
mechanical/tibia.scad

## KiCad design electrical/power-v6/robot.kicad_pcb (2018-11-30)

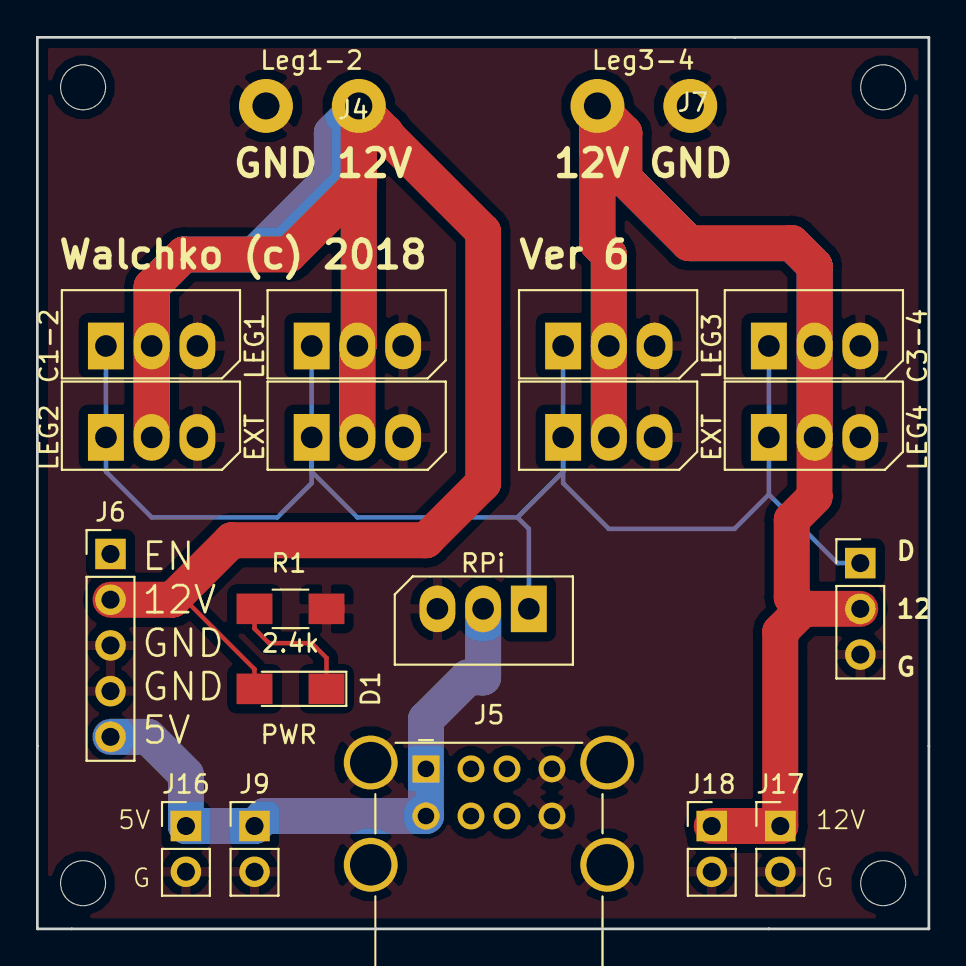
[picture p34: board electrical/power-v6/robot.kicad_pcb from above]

Board: 2 copper layers, 49.5 x 49.5 mm, 21 parts (1 on the bottom side), 6 nets.

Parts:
D1: PWR; LED_1206_HandSoldering
J1: C1-2; Molex_SPOX-5267_22-03-5035_03x2.54mm_Straight
J2: RPi; Molex_SPOX-5267_22-03-5035_03x2.54mm_Straight
J3: Data; Pin_Header_Straight_1x03_Pitch2.54mm
J4: Leg1-2; WireConnection_1.50mmDrill
J5: USB_A_2_PORT; USB_A_Wuerth_61400826021_Horizontal_Stacked
J6: 5V Pwr; Pin_Header_Straight_1x05_Pitch2.54mm
J7: Leg3-4; WireConnection_1.50mmDrill
J8: LEG1; Molex_SPOX-5267_22-03-5035_03x2.54mm_Straight
J9, J16: 5V; Pin_Header_Straight_1x02_Pitch2.54mm
J10: LEG2; Molex_SPOX-5267_22-03-5035_03x2.54mm_Straight
J11, J13: EXT; Molex_SPOX-5267_22-03-5035_03x2.54mm_Straight
J12: LEG4; Molex_SPOX-5267_22-03-5035_03x2.54mm_Straight
J14: C3-4; Molex_SPOX-5267_22-03-5035_03x2.54mm_Straight
J15: LEG3; Molex_SPOX-5267_22-03-5035_03x2.54mm_Straight
J17, J18: 12V; Pin_Header_Straight_1x02_Pitch2.54mm
LOGO1: Logo_Open_Hardware_Large; OSHW-Logo2_24.3x20mm_SilkScreen
R1: 2.4k; R_1206_HandSoldering

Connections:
+5V: J2.2, J5.1, J5.5, J6.5, J9.1, J16.1
DATA: J1.1, J2.1, J3.1, J8.1, J10.1, J11.1, J12.1, J13.1, J14.1, J15.1
GND: J1.3, J2.3, J3.3, J4.1, J5.4, J5.8, J5.9, J6.3, J6.4, J7.1, J8.3, J9.2, J10.3, J11.3, J12.3, J13.3, J14.3, J15.3, J16.2, J17.2, J18.2, R1.2
unnamed: D1.1, R1.1
unnamed: D1.2, J1.2, J4.2, J6.2, J8.2, J10.2, J11.2
unnamed: J3.2, J7.2, J12.2, J13.2, J14.2, J15.2, J17.1, J18.1

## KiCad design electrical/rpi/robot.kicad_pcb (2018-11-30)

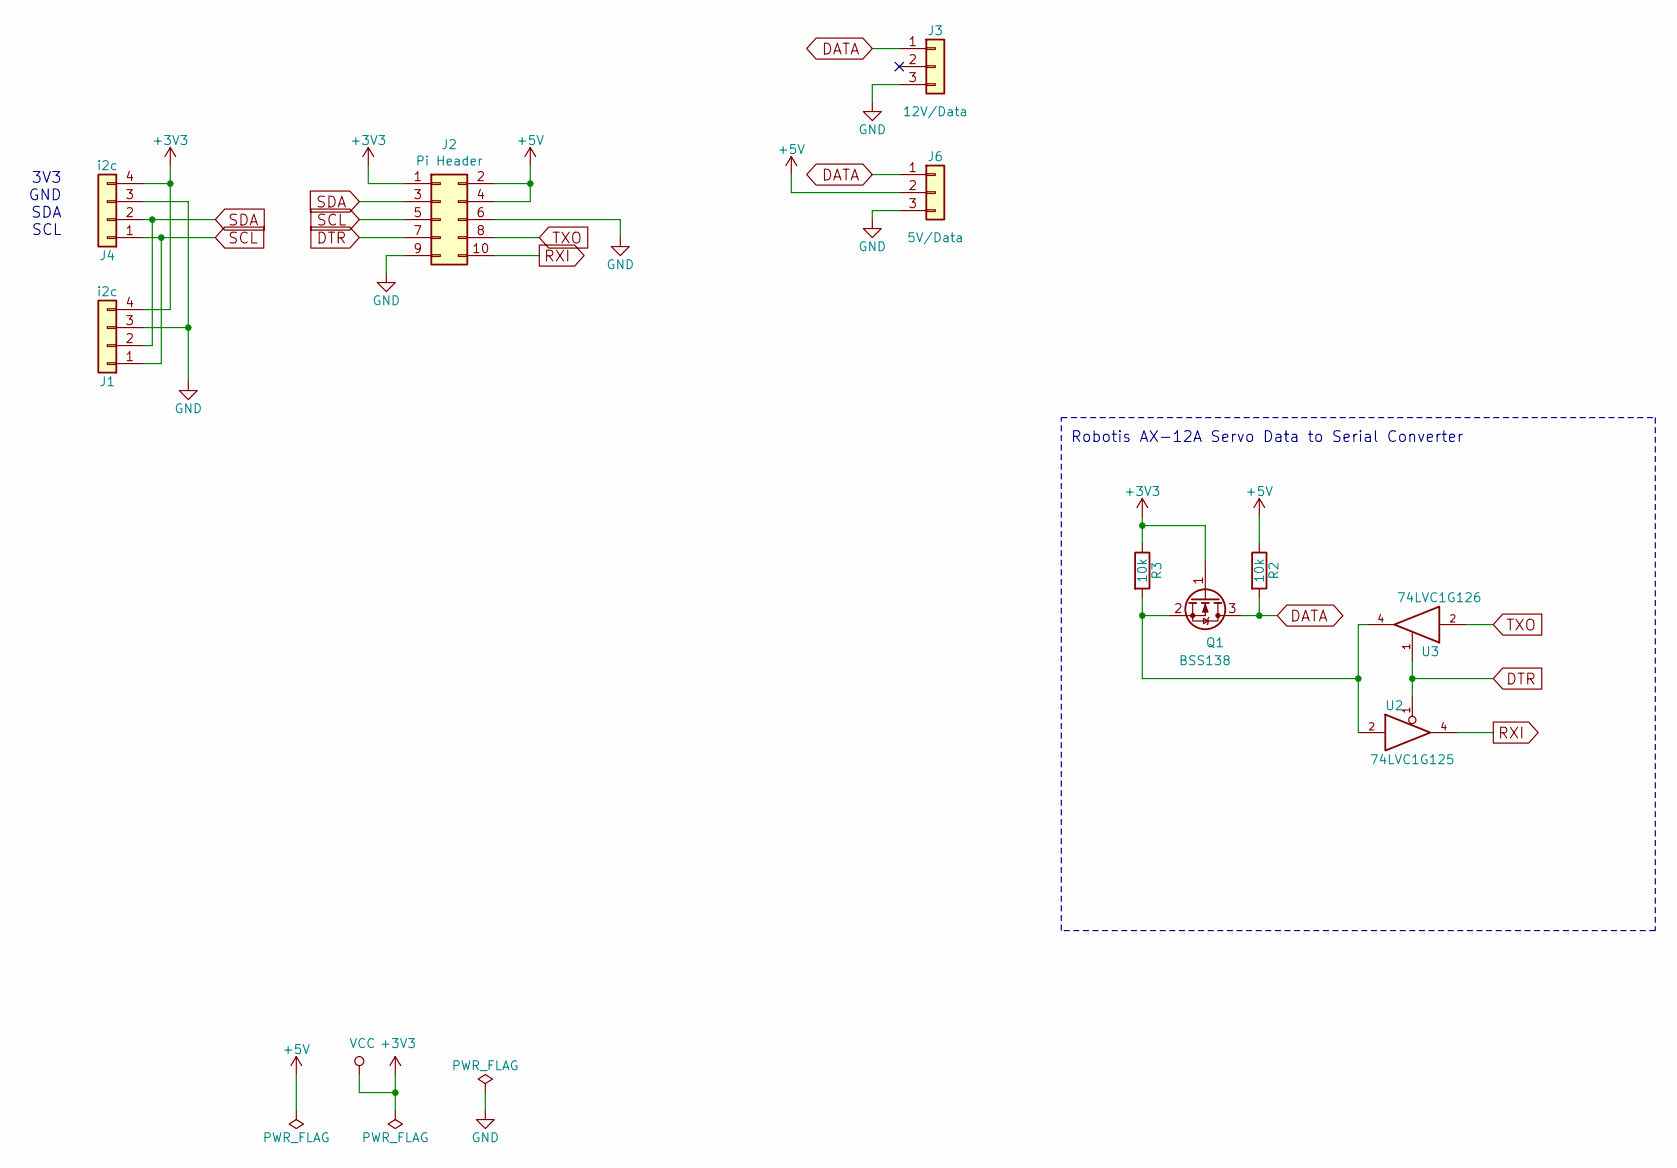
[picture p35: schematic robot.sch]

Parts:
J1, J4: i2c; Pin_Header_Straight_1x04_Pitch2.54mm
J2: Pi Header; Pin_Header_Straight_2x05_Pitch2.54mm
J3: 12V/Data; Molex_SPOX-5267_22-03-5035_03x2.54mm_Straight
J6: 5V/Data; Molex_SPOX-5267_22-03-5035_03x2.54mm_Straight
Q1: BSS138; SOT-23
R2, R3: 10k; R_1206_HandSoldering
U2: 74LVC1G125; SOT-23-5_HandSoldering
U3: 74LVC1G126; SOT-23-5_HandSoldering

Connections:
+3V3: J1.4, J2.1, J4.4, Q1.1 (G), R3.1, U2.5 (VCC), U3.5 (VCC)
+5V: J2.2, J2.4, J6.2, R2.1
DATA: J3.1, J6.1, Q1.3 (D), R2.2
DTR: J2.7, U2.1, U3.1
GND: J1.3, J2.6, J2.9, J3.3, J4.3, J6.3, U2.3 (GND), U3.3 (GND)
unnamed: Q1.2 (S), R3.2, U2.2, U3.4
RXI: J2.10, U2.4
SCL: J1.1, J2.5, J4.1
SDA: J1.2, J2.3, J4.2
TXO: J2.8, U3.2

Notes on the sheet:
Robotis AX-12A Servo Data to Serial Converter
3V3 GND SDA SCL

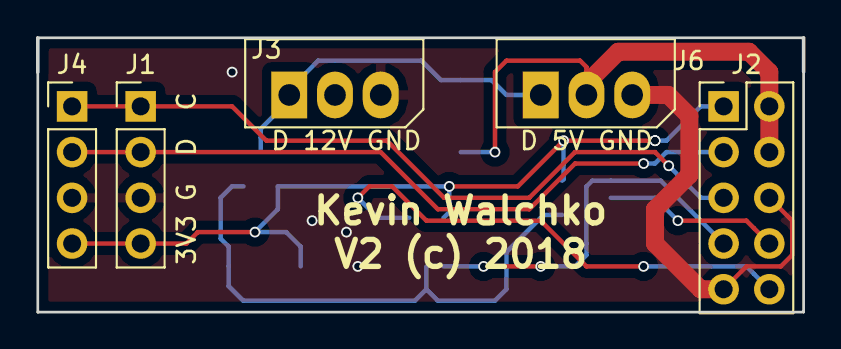
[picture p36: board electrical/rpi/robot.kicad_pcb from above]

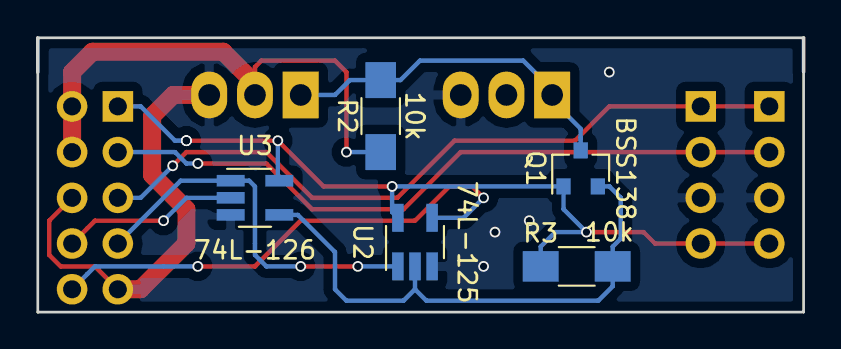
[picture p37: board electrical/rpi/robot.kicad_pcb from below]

Board: 2 copper layers, 42.5 x 15.2 mm, 10 parts (5 on the bottom side), 10 nets.

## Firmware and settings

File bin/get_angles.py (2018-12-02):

#!/usr/bin/env python3

##############################################
# The MIT License (MIT)
# Copyright (c) 2016 Kevin Walchko
# see LICENSE for full details
##############################################
from __future__ import print_function
from pyservos import Packet
from pyservos import ServoSerial
import sys
import time
import pyservos
from collections import OrderedDict


def makeAngleReadPacket(id):
    servo = Packet(pyservos.AX12)  # remove
    pkt = servo.makeReadPacket(id, 36,2)  # self.base.makeReadPacket()
    return pkt


def get(port, IDs, bcm_pin, retry=3):
    """
    Sends a ping packet to ID's from 0 to maximum and prints out any returned
    messages.
    Actually send a broadcast and will retry (resend) the ping 3 times ...
    """
    valid_return = False

    s = ServoSerial(port, pi_pin=bcm_pin)

    try:
        s.open()
    except Exception as e:
        print('-'*40)
        print(sys.argv[0], ':')
        print(e)
        exit(1)

    servo = Packet(pyservos.AX12)

    found_servos = {}

    # print("read:")
    for id in IDs:
        # print(id, end=' ')
        pkt = makeAngleReadPacket(id)
        s.write(pkt)

        valid_return = False

        # as more servos add up, I might need to increase the cnt number???
        for cnt in range(retry):
            ans = s.read()

            if ans:
                valid_return = True
                pkts = servo.decodePacket(ans)
                # print(pkts)
                for pkt in pkts:
                    if pkt[:5] == [0xff,0xff,id,4,0]:
                        angle = ((pkt[6] << 8) + pkt[5]) * 0.29  # cnts to deg
                        found_servos[id] = angle
                # print('Found')
                break
            if not valid_return:
                print(id, 'ERROR: Could not read servo angle')

            time.sleep(0.1)

    s.close()

    return valid_return, found_servos


if __name__ == "__main__":
    port = '/dev/serial0'
    ok, servos = get(port, range(1,17), 17)

    if ok:
        servos = OrderedDict(servos)

        # print('-[Servos 0-300 deg]---------------------------')
        for i, (k, v) in enumerate(servos.items()):
            if i in [0,4,8,12]:
                print("==[ Leg {:.0f} ]------------------".format(i/4))
            print("  {:.<10} {:5.1f} deg".format(k,v))
    else:
        print('No servos found')

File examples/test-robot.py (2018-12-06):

#!/usr/bin/env python3
##############################################
# The MIT License (MIT)
# Copyright (c) 2018 Kevin Walchko
# see LICENSE for full details
##############################################

from __future__ import print_function
from __future__ import division
from multiped import Engine
# from multiped import DiscreteRippleGait
from multiped import Kinematics4
from pyservos import AX12
import time
from math import pi, sqrt
from enum import IntFlag
import platform
import sys
from Gait2 import Discrete
from plotting import rplot, rplot2, plot_body_frame
from pprint import pprint

"""
need:

      cmd      3d pts      DH angles        servo packet
robot --> gait -----> legs --------> engine -----------> servos

robot:
- sensors
- AI
- Holds:
    - kinematics
    - gait
    - engine
- knows:
    - command
    - 3d points
    - dh angles

Kinematics
- init: link lengths
- F/I Kinematics

Gait:
- init: neutral pos
- step sequence

Engine:
- init: servoType, current pos, servoOffsets, serial port
- serial connection
- servo protocol (ax12, xl430, rcservo, etc)
- DH2ServoAngles

Issues:
--------
- gait should drive speed, right now kinematics sets all movements the same
- transition from N->A and A->N
    - which class knows what
    - need to shift body CM
"""


class RobotTest(object):
    def __init__(self):
        bcm_pin = None
        if True:  # manual override for testing - don't actually talk to servos
            ser = 'fake'
        elif platform.system() == 'Darwin':
            ser = '/dev/tty.usbserial-A506BOT5'
        elif platform.system() == 'Linux':
            ser = '/dev/serial0'
            bcm_pin = 17
        else:
            raise Exception('Your OS is not supported')

        data = {
            # [ length, (limit_angles), offset_angle] - units:mm or degrees
            # 'coxa':   [52, [-90, 90], 150],
            # 'femur':  [90, [-90, 90], 123],   # fixme
            # 'tibia':  [89, [-90, 120], 194],  # fixme
            # 'tarsus': [90, [-90, 90], 167],
            'numLegs': 4,          # helps?
            'numServosPerLeg': 4,  # helps?
            'coxa':   [52, 150],   # length [mm], offset [deg]
            'femur':  [90, 123],
            'tibia':  [89, 194],
            'tarsus': [90, 167],

            'sit': (80, 0, 1,),     # foot position [mm]
            'stand': (120, 0, -70), # foot position [mm]

            # engine
            # types: 1:ax12 2:xl320 4:xl430
            'servoType': 1,  # switch to IntFlags
            'serialPort': ser,
            'bcm_pin': bcm_pin
        }

        self.positions = {
            'stand': data['stand'],
            'sit': data['sit']
        }

        self.kinematics = Kinematics4(data)
        self.gait = Discrete(self.positions['stand'])

        self.engine = Engine(data, AX12)

        # where are the feet currently ... angles?
        self.currentAngles = {}  # DH angles
        dh_angles = self.engine.getCurrentAngles()
        self.currentAngles = dh_angles  # value??
        # where are the feet currently ... (x,y,z)?
        self.currentFeet = {}  # (x,y,z)
        for i, angles in dh_angles.items():
            # print(angles)
            self.currentFeet[i] = list(self.kinematics.forward(*angles))
        print("current feet",self.currentFeet)
        # self.stand(self.currentFeet)

    def __del__(self):
        current = self.getFeetPosition()
        # self.sit(current)

    def getFeetPosition(self):
        """
        return {0:(x,y,z), 1:(x,y,z), ...}
        """
        dh_angles = self.engine.getCurrentAngles()
        currentFeet = {}  # (x,y,z)
        for i, angles in dh_angles.items():
            # print(angles)
            currentFeet[i] = list(self.kinematics.forward(*angles))
        print("current feet",currentFeet)
        return currentFeet

    def walk(self):
        print(" <<<==========  Walk  ==========>>>")
        # predefined walking path
        # x, y, rotation
        CmdState = IntFlag('CmdState', 'linear rotational neutral')
        state = CmdState.neutral
        path = [
            [1.0, 0.0, 0],
            # [1.0, 0, 0],
            # [1.0, 0, 0],
            # [1.0, 0, 0],
            # [1.0, 0, 0],
            # [1.0, 0, 0],
            # [1.0, 0, 0],
            # [1.0, 0, 0],
            # [1.0, 0, 0],
            # [1.0, 0, 0],
            # [0, 0, pi/4],
            # [0, 0, pi/4],
            # [0, 0, pi/4],
            # [0, 0, -pi/4],
            # [0, 0, -pi/4],
            # [0, 0, -pi/4],
            # [-1.0, 0, 0],
            # [-1.0, 0, 0],
            # [-1.0, 0, 0],
            # [-1.0, 0, 0],
            # [-1.0, 0, 0],
            # [-1.0, 0, 0],
            # [-1.0, 0, 0],
            # [-1.0, 0, 0],
            # [-1.0, 0, 0],
            # [-1.0, 0, 0],
        ]

        # cp = self.getFeetPosition()
        self.toGait()
        return

        for cmd in path:
            # if cmd[2] == 0:
            #     if state == CmdState.neutral or state == CmdState.rotational:
            #         self.toGait()
            #         state = CmdState.linear
            # else:
            #     if state == CmdState.linear:
            #         self.toNeutral()
            #         state = CmdState.rotational

            pts = self.gait.command(cmd)        # get 3d feet points

            # # save 3d points
            # for i in pts.keys():
            #     self.currentFeet[i] = pts[i][-1]
            #
            # plot_body_frame(pts,1)
            #
            # # pts = (x,y,z) for each leg for the whole cycle
            # # speed = max speed seen by any joint, most likely it will be lower
            angles_speeds = self.kinematics.generateDHAngles(pts, 200)  # get servo angles

            # rplot2(angles_speeds[0])

            # only move 1 leg, remove others from commands
            # if False:
            #     angles_speeds.pop(2)
            #     angles_speeds.pop(1)
            #     angles_speeds.pop(3)

            self.engine.moveLegsGait4(angles_speeds)  # send commands to servos

        # self.toNeutral()

    def step(self, leg, p1, p2, lift):
        """
        Pick the foot up and set it down
        leg - which leg number 0-3
        p1 - start (x,y,z)
        p2 - stop (x,y,z)
        lift - how high to lift the foot
        """
        pass

    def toNeutral(self, speed=100):
        return

    def liftOne(self, moveleg, curr, fin):
        steps = {0:[],1:[],2:[],3:[]}
        # for leg in range(4):
        #     steps[leg].append(cu[leg])

        for leg in range(4):
            if leg == moveleg:
                # current position
                steps[leg].append(curr[leg])

                # lift curr
                c = curr[leg].copy()
                c[2] = 0
                steps[leg].append(c)

                # lift final
                f = list(fin[leg])
                f[2] = 0
                steps[leg].append(f)
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

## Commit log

2018-11-27 new board :electric_plug: :bento:
    [robot-B.Cu.gbr, robot-B.Mask.gbr, robot-B.SilkS.gbr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]
2018-12-01 servos read :lizard: :bento:
    [get_angles.py, test-robot.py]

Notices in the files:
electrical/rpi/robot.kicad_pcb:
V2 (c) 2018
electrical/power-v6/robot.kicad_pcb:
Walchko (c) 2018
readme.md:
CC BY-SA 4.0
